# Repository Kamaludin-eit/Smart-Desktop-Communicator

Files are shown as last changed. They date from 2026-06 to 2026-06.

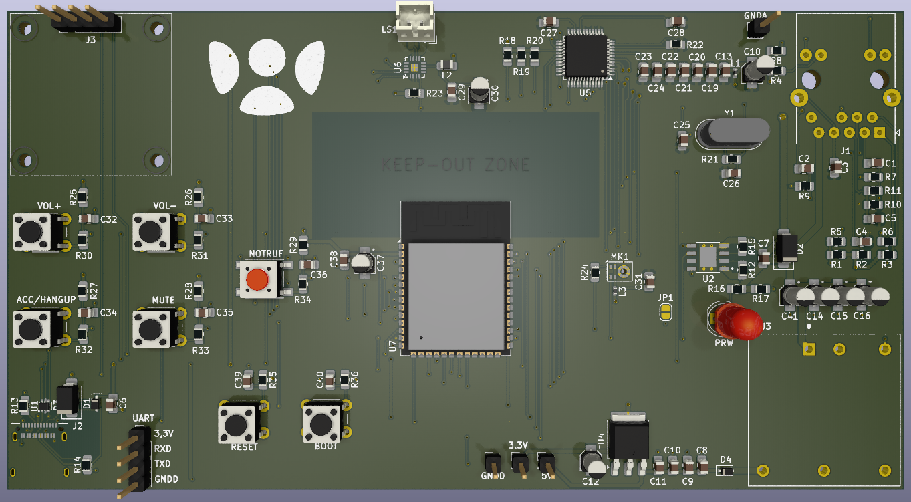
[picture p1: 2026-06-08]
docs/images/Chrood_PCB_image.png

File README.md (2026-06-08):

### Smart Desktop Communicator – Design-Dokumentation

**Rev 1.0 | Kamaludin Ali**

\---

#### Übersicht

ESP32-S3-basiertes stationäres IP-Telefon mit PoE-Versorgung, Wired Ethernet,
I2S-Audio und OLED-Display. 4-lagige PCB (150 × 80 mm).

\---

#### Wichtigste Design-Entscheidungen

##### 1\. Mikrocontroller – ESP32-S3-WROOM-1

* Dual-Core LX7, 16 MB Flash, 8 MB PSRAM, 2.4 GHz WLAN integriert
* Natives USB Serial/JTAG auf GPIO19/20 – kein separater USB-UART-Chip nötig
* I2S-Peripheral für DAC (MAX98357A) und PDM-Mikrofon (IM69D120) separat nutzbar
* SPI-Peripheral für W5500 Ethernet-Controller

##### 2\. PoE-Versorgung – TPS2378DDA + PDQE30-Q48-S5-D

* TPS2378DDA: IEEE 802.3at Type-2 PD-Controller (bis 30 W)
* Kein integrierter DC/DC – externer isolierter Wandler PDQE30 (48 V → 5 V, 30 W)
* Isolation trennt PWR\_GND (48 V-Seite) vollständig von GNDD/GNDA (Systemseite)
* Alternativversorgung via USB-C (5 V) mit Schottky-Dioden-OR-Schaltung#

##### 3\. RJ45-Connector – ARJP11A-MASA-B-A-EMU2 (Abracon)

* Integrierte Magnetics, Center-Tap, eingebauter Brückengleichrichter
* PRW+ (Pin 9) / PRW− (Pin 10): rektifizierte PoE-Spannung direkt abgreifbar
* Kein externer Brückengleichrichter oder separates Magnetics-Modul nötig
* Integrierte Status-LEDs (Link/Activity)

##### 4\. Ethernet – W5500

* Hardware-TCP/IP-Stack – entlastet ESP32-S3 vollständig
* SPI-Interface (bis 80 MHz), geringer Softwareaufwand

##### 5\. Audio-Ausgabe – MAX98357A

* I2S DAC + Class-D 3 W Verstärker in einem IC
* BTL-Ausgang: keine DC-Koppelkondensatoren am Lautsprecher nötig
* PVDD über Ferritperle L3 (600 Ω @ 100 MHz, 1 A) von 5V-Rail entkoppelt
* 3.3V-Logiksignale vom ESP32 kompatibel (VIH\_min = 1.5 V)
* Lautsprecher extern im Gehäuse montiert (akustische Echo-Minimierung)

##### 6\. Audio-Eingang – IM69D120 (Infineon)

* MEMS-Mikrofon mit PDM-Ausgang, SNR 69 dB, AOP 120 dB SPL
* Nativ vom ESP32-S3 PDM-Peripheral unterstützt
* VDD über eigene Ferritperle L4 (600 Ω @ 100 MHz, 50 mA) von VCCA\_MIC
* Software-AEC (Acoustic Echo Cancellation) via ESP-ADF

##### 7\. Massekonzept – 2 getrennte GND-Domänen

|Domäne|Verbindung|Komponenten|
|-|-|-|
|GNDD|Solder Jumper Pin 2 |ESP32, W5500 digital, Tasten, LEDs|
|GNDA|Solder Jumper Pin 1|W5500 PHY, IM69D120, MAX98357A, Quarz|

##### 8\. 4-Lagen PCB-Aufbau (150 × 80 mm)

|Lage|Inhalt|
|-|-|
|Layer 1 (Top)|Bauteile + Signale + GNDA-Kupferfläche|
|Layer 2 (In1)|+3,3V  |
|Layer 3 (In2)|GNDD-Kupferfläche|
|Layer 4 (Bottom)|Signale + GNDA-Kupferfläche|

* Digitale GND-Pads auf Top-Layer über Vias mit GNDD (In1) verbunden
* Analoge Komponenten direkt auf GNDA-Fläche (Top-Layer)

##### 9\. Versorgungsschienen

|Schiene|Quelle|Verbraucher|
|-|-|-|
|+48V\_POE|PRW+ via SMAJ58A|TPS2378DDA VDD|
|+5V|PDQE30 Ausgang|MAX98357A, AMS1117|
|+3.3V (VCCD)|AMS1117-3.3|ESP32, W5500 digital, Tasten, LEDs|
|VCCA\_ETH|VCCD via FB\_ETH (600Ω)|W5500 VCCA|
|VCCA\_MIC|VCCD via FB\_MIC (600Ω)|IM69D120 VDD|

### 

##### 10\. ESD-Schutz

|Interface|Schutz|
|-|-|
|PoE 48V|SMAJ58A (unidirektional, 58V)|
|USB-C VBUS|SMAJ5.0A (unidirektional, 5V)|
|USB-C D+/D−|USBLC6-2P6 (Low-C, bidirektional)|
|Ethernet TX/RX|Magnetics-Isolation im ARJP11A|

### 

##### 11\. USB-C – Amphenol 12401610E4#2A

* CC1/CC2: je 5.1 kΩ nach GNDD (5V UFP-Erkennung, kein PD-Controller nötig)
* Schottky-Diode OR-ing mit PoE-Versorgung
* D+/D−: direkt an ESP32 GPIO19/GPIO20 (natives USB JTAG/Serial)

##### 12\. HMI

* SSD1306 OLED 0.96" (128×64, I2C): Anrufstatus, IP, Uhrzeit
* 5 Taster: Annehmen/Auflegen, Vol+, Vol−, Stummschalten, Notruf
* 1 Status-LEDs:  Power(rot)
* Hardware-Entprellung: RC-Glied (100 kΩ + 1 µF) pro Taster

\---

#### Geplante Firmware-Architektur

* **ESP-IDF** v5.x + **ESP-ADF** (Audio Development Framework)
* SIP-Stack: sikorapatryk/sip-call oder OLIMEX/sip\_phone\_example als Referenz
* Codec: G.711 µ-law (PCMU, Payload Type 0)
* AEC: ESP-ADF eingebaut
* W5500-Treiber: arduino-ethernet oder esp-idf-w5500

\---

#### Wählscheibe

Nicht vorgesehen – Anrufsteuerung erfolgt über SIP-Server/PBX-Integration (z.B. FreePBX, Asterisk).

\---

## Revision History

|Rev|Datum|Änderung|
|-|-|-|
|1.0|2026-05|Erstversion|

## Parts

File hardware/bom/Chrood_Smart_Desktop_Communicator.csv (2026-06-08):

Reference | Value | Datasheet | Footprint | Qty | DNP
C1,C2 | 6,8nF | ~ | Capacitor_SMD:C_0805_2012Metric_Pad1.18x1.45mm_HandSolder | 2
C3 | 1nF | ~ | Capacitor_SMD:C_0805_2012Metric_Pad1.18x1.45mm_HandSolder | 1
C4 | 22nF | ~ | Capacitor_SMD:C_0805_2012Metric_Pad1.18x1.45mm_HandSolder | 1
C5 | 10nF | ~ | Capacitor_SMD:C_0805_2012Metric_Pad1.18x1.45mm_HandSolder | 1
C6 | 100nF | ~ | Capacitor_SMD:C_0805_2012Metric_Pad1.18x1.45mm_HandSolder | 1
C7,C8,C9,C10,C29,C31 | 100n | ~ | Capacitor_SMD:C_0805_2012Metric_Pad1.18x1.45mm_HandSolder | 6
C11,C13,C19,C20,C21,C22,C23,C24,C38,C39,C40 | 0,1u | ~ | Capacitor_SMD:C_0805_2012Metric_Pad1.18x1.45mm_HandSolder | 11
C12 | 47u | ~ | Capacitor_SMD:CP_Elec_3x5.3 | 1
C14,C15,C16,C41 | 22u | ~ | Capacitor_SMD:CP_Elec_3x5.3 | 4
C18,C30,C37 | 10u | ~ | Capacitor_SMD:CP_Elec_3x5.3 | 3
C25,C26 | 18p | ~ | Capacitor_SMD:C_0805_2012Metric_Pad1.18x1.45mm_HandSolder | 2
C27 | 10n | ~ | Capacitor_SMD:C_0805_2012Metric_Pad1.18x1.45mm_HandSolder | 1
C28 | 4,7u | ~ | Capacitor_SMD:C_0805_2012Metric_Pad1.18x1.45mm_HandSolder | 1
C32,C33,C34,C35,C36 | 2,2u | ~ | Capacitor_SMD:C_0805_2012Metric_Pad1.18x1.45mm_HandSolder | 5
D1,D4 | BAT54J | https://assets.nexperia.com/documents/data-sheet/BAT54J.pdf | Diode_SMD:D_SOD-323F | 2
D2 | SMAJ58A | https://www.littelfuse.com/media?itemid=75e32973-b177-4ee3-a0ff-cedaf1abdb93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 | Diode_SMD:D_SMA | 1
D3 | SMAJ5.0A | https://www.littelfuse.com/media?itemid=75e32973-b177-4ee3-a0ff-cedaf1abdb93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 | Diode_SMD:D_SMA | 1
D5 | LED | ~ | LED_THT:LED_D5.0mm | 1
J1 | RJ45_Abracon_ARJP11A-MASA-B-A-EMU2 | https://abracon.com/Magnetics/lan/ARJP11A.PDF | Connector_RJ:RJ45_Abracon_ARJP11A-MA_Horizontal | 1
J2 | USB_C_Receptacle_USB2.0_14P | https://www.usb.org/sites/default/files/documents/usb_type-c.zip | Connector_USB:USB_C_Receptacle_Amphenol_12401610E4-2A | 1
J3,J4 | Conn_01x04_Pin | ~ | Connector_PinHeader_2.54mm:PinHeader_1x04_P2.54mm_Vertical | 2
L1,L2,L3 | 600Ohm@100MHz | ~ | -- verschiedene Werte -- | 3
LS1 | Speaker | ~ | Connector_JST:JST_PH_B2B-PH-K_1x02_P2.00mm_Vertical | 1
MK1 | IM69D120 | https://www.infineon.com/dgdl/Infineon-IM69D120-DS-v01_00-EN.pdf?fileId=5546d462602a9dc801607a0e41a01a2b | Sensor_Audio:Infineon_PG-LLGA-5-1 | 1
R1,R2,R3 | 10 | ~ | Resistor_SMD:R_0805_2012Metric_Pad1.20x1.40mm_HandSolder | 3
R4,R8,R25,R26,R27,R28,R29 | 1k | ~ | Resistor_SMD:R_0805_2012Metric_Pad1.20x1.40mm_HandSolder | 7
R5,R6,R7,R9,R10,R11 | 33 | ~ | Resistor_SMD:R_0805_2012Metric_Pad1.20x1.40mm_HandSolder | 6
R12 | 24k9 | ~ | Resistor_SMD:R_0805_2012Metric_Pad1.20x1.40mm_HandSolder | 1
R13,R14 | 5,1k | ~ | Resistor_SMD:R_0805_2012Metric_Pad1.20x1.40mm_HandSolder | 2
R15 | 63R4 | ~ | Resistor_SMD:R_0805_2012Metric_Pad1.20x1.40mm_HandSolder | 1
R16 | 32k4 | ~ | Resistor_SMD:R_0805_2012Metric_Pad1.20x1.40mm_HandSolder | 1
R17 | 15k | ~ | Resistor_SMD:R_0805_2012Metric_Pad1.20x1.40mm_HandSolder | 1
R18,R19,R20,R35,R36 | 10k | ~ | Resistor_SMD:R_0805_2012Metric_Pad1.20x1.40mm_HandSolder | 5
R21 | 1M | ~ | Resistor_SMD:R_0805_2012Metric_Pad1.20x1.40mm_HandSolder | 1
R22 | 12k | ~ | Resistor_SMD:R_0805_2012Metric_Pad1.20x1.40mm_HandSolder | 1
R23 | 100k | ~ | Resistor_SMD:R_0805_2012Metric_Pad1.20x1.40mm_HandSolder | 1
R24 | 100 | ~ | Resistor_SMD:R_0805_2012Metric_Pad1.20x1.40mm_HandSolder | 1
R30,R31,R32,R33,R34 | 4,7k | ~ | Resistor_SMD:R_0805_2012Metric_Pad1.20x1.40mm_HandSolder | 5
SW1 | Vol+ | ~ | Button_Switch_THT:SW_PUSH_6mm | 1
SW2 | Vol- | ~ | Button_Switch_THT:SW_PUSH_6mm | 1
SW3 | Accept/Hang up | ~ | Button_Switch_THT:SW_PUSH_6mm | 1
SW4 | Mute | ~ | Button_Switch_THT:SW_PUSH_6mm | 1
SW5 | Notruf | ~ | Button_Switch_SMD:SW_SPST_PTS645 | 1
SW6,SW7 | SW_Push | ~ | Button_Switch_THT:SW_PUSH_6mm | 2
TP1,TP2,TP3,TP4 | TestPoint | ~ | Connector_PinHeader_2.54mm:PinHeader_1x01_P2.54mm_Vertical | 4
U1 | USBLC6-2P6 | https://www.st.com/resource/en/datasheet/usblc6-2.pdf | Package_TO_SOT_SMD:SOT-666 | 1
U2 | TPS2378DDA |  | TPS2378DDA:VREG_LM5017MR_NOPB | 1
U3 | PDQ30-Q48-S5-D |  | PDQ30-Q48-S5-D:CONV_PDQ30-Q48-S5-D | 1
U4 | AMS1117CD-3.3 | http://www.advanced-monolithic.com/pdf/ds1117.pdf | Package_TO_SOT_SMD:TO-252-3_TabPin2 | 1
U5 | W5500 | http://wizwiki.net/wiki/lib/exe/fetch.php/products:w5500:w5500_ds_v109e.pdf | Package_QFP:LQFP-48_7x7mm_P0.5mm | 1
U6 | MAX98357A | https://www.analog.com/media/en/technical-documentation/data-sheets/MAX98357A-MAX98357B.pdf | Package_DFN_QFN:TQFN-16-1EP_3x3mm_P0.5mm_EP1.23x1.23mm | 1
U7 | ESP32-S3-WROOM-1 | https://www.espressif.com/sites/default/files/documentation/esp32-s3-wroom-1_wroom-1u_datasheet_en.pdf | RF_Module:ESP32-S3-WROOM-1 | 1
Y1 | 25MHz | ~ | Crystal:Crystal_HC49-4H_Vertical | 1

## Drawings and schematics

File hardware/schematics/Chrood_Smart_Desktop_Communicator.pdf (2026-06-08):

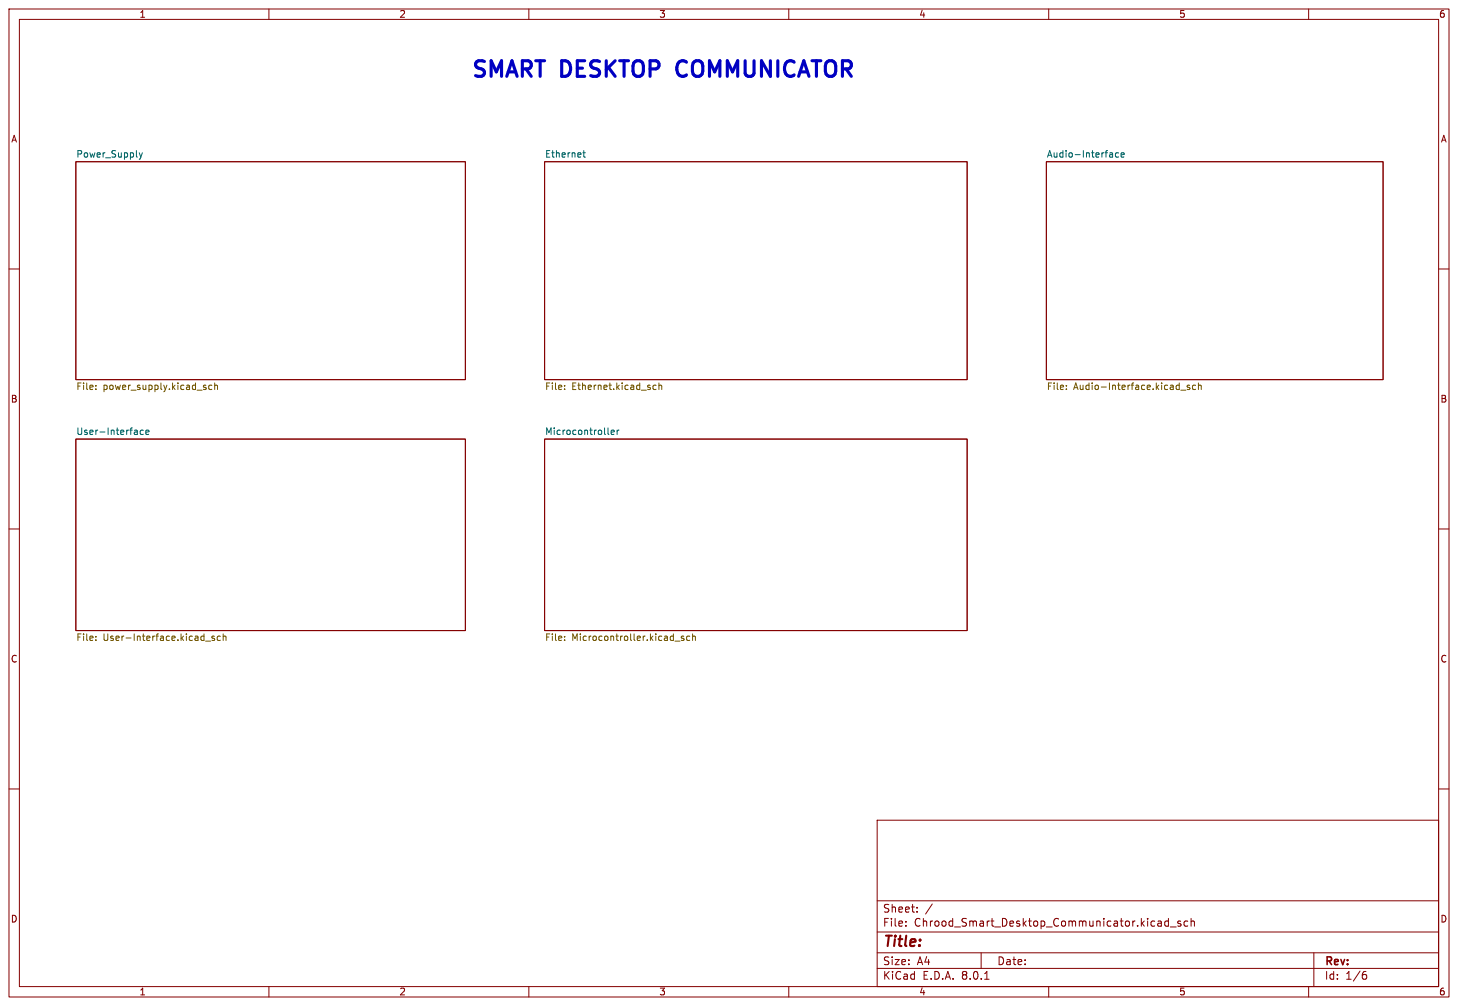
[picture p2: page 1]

User-Interface File: User-Interface.kicad_sch

Id: 1/6 Title: File: Chrood_Smart_Desktop_Communicator.kicad_sch Sheet: /

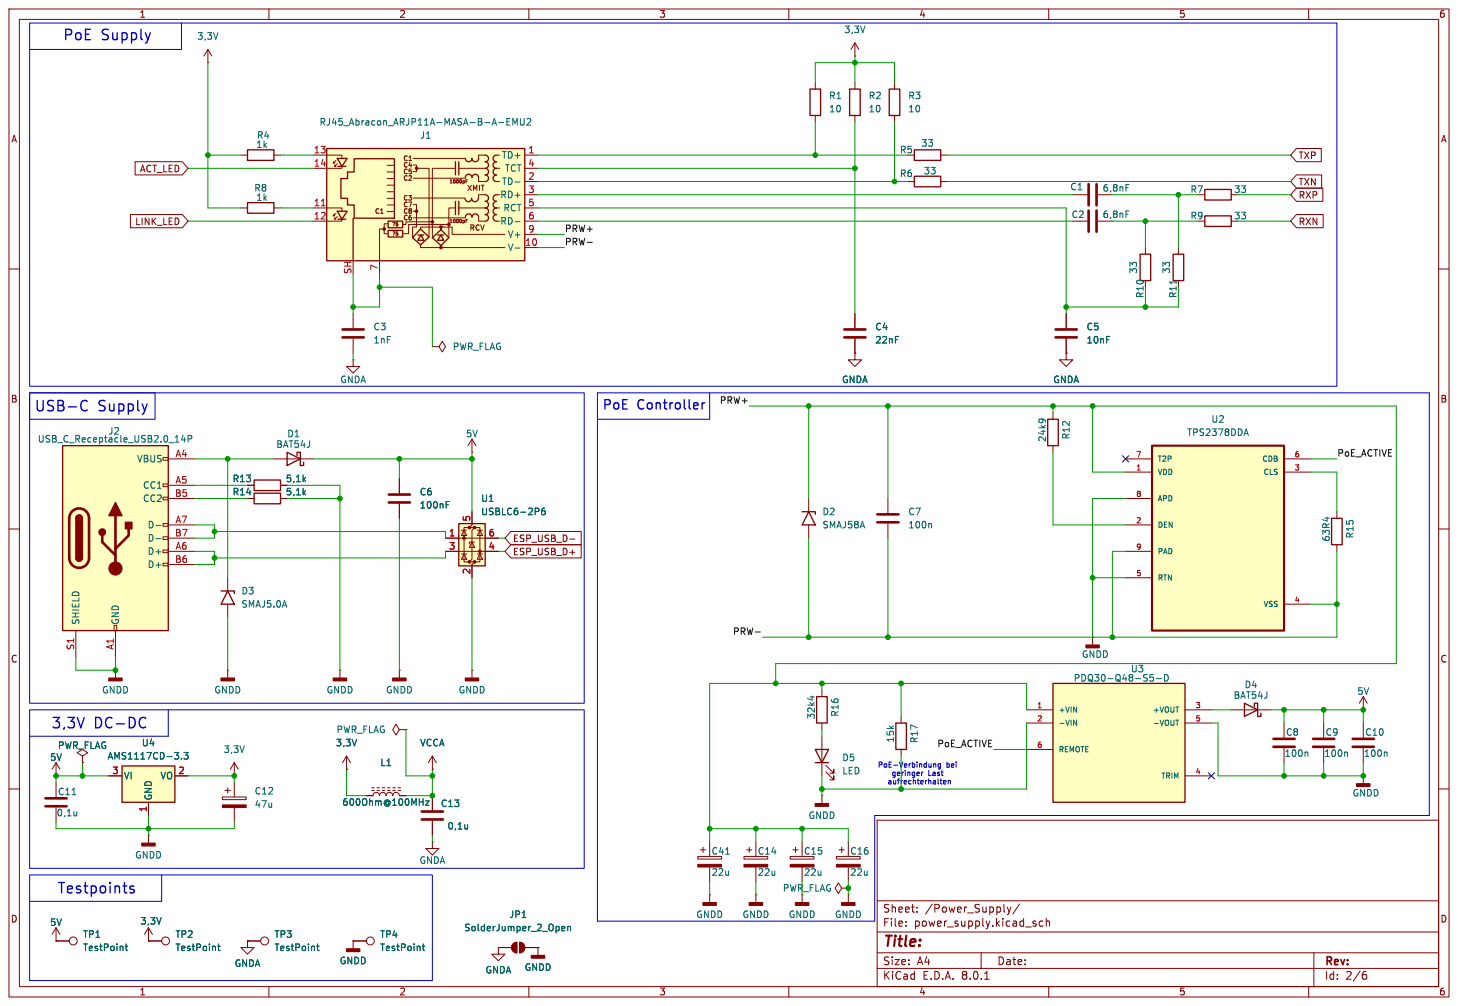
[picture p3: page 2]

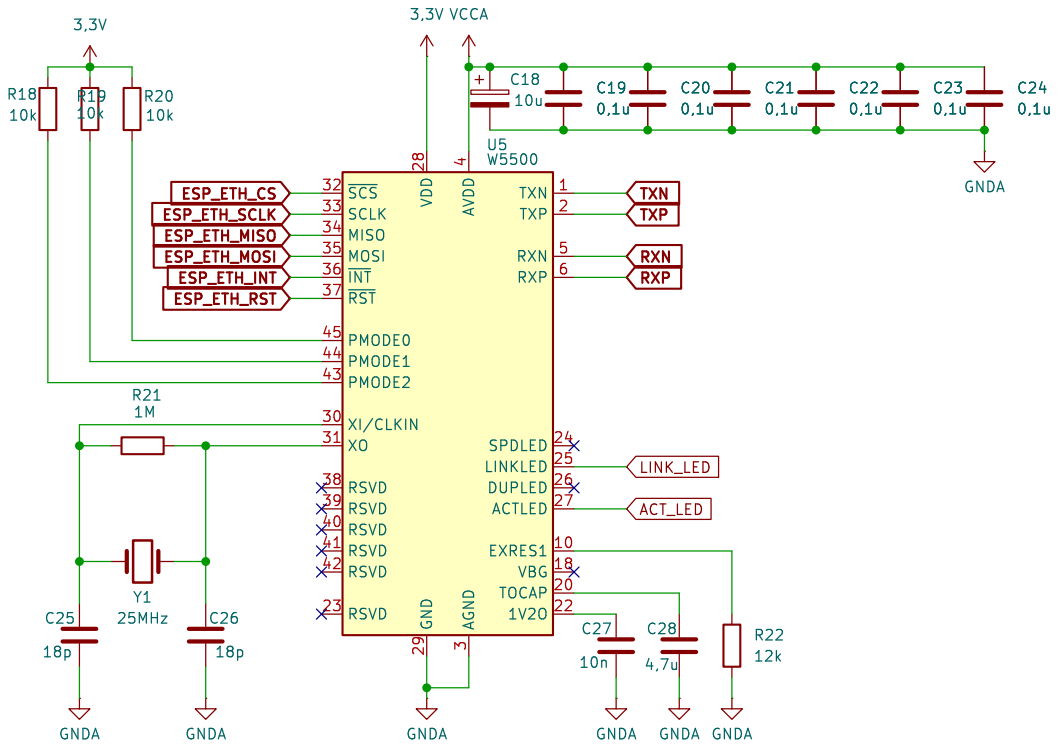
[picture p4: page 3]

Id: 3/6 Title: File: Ethernet.kicad_sch Sheet: /Ethernet/

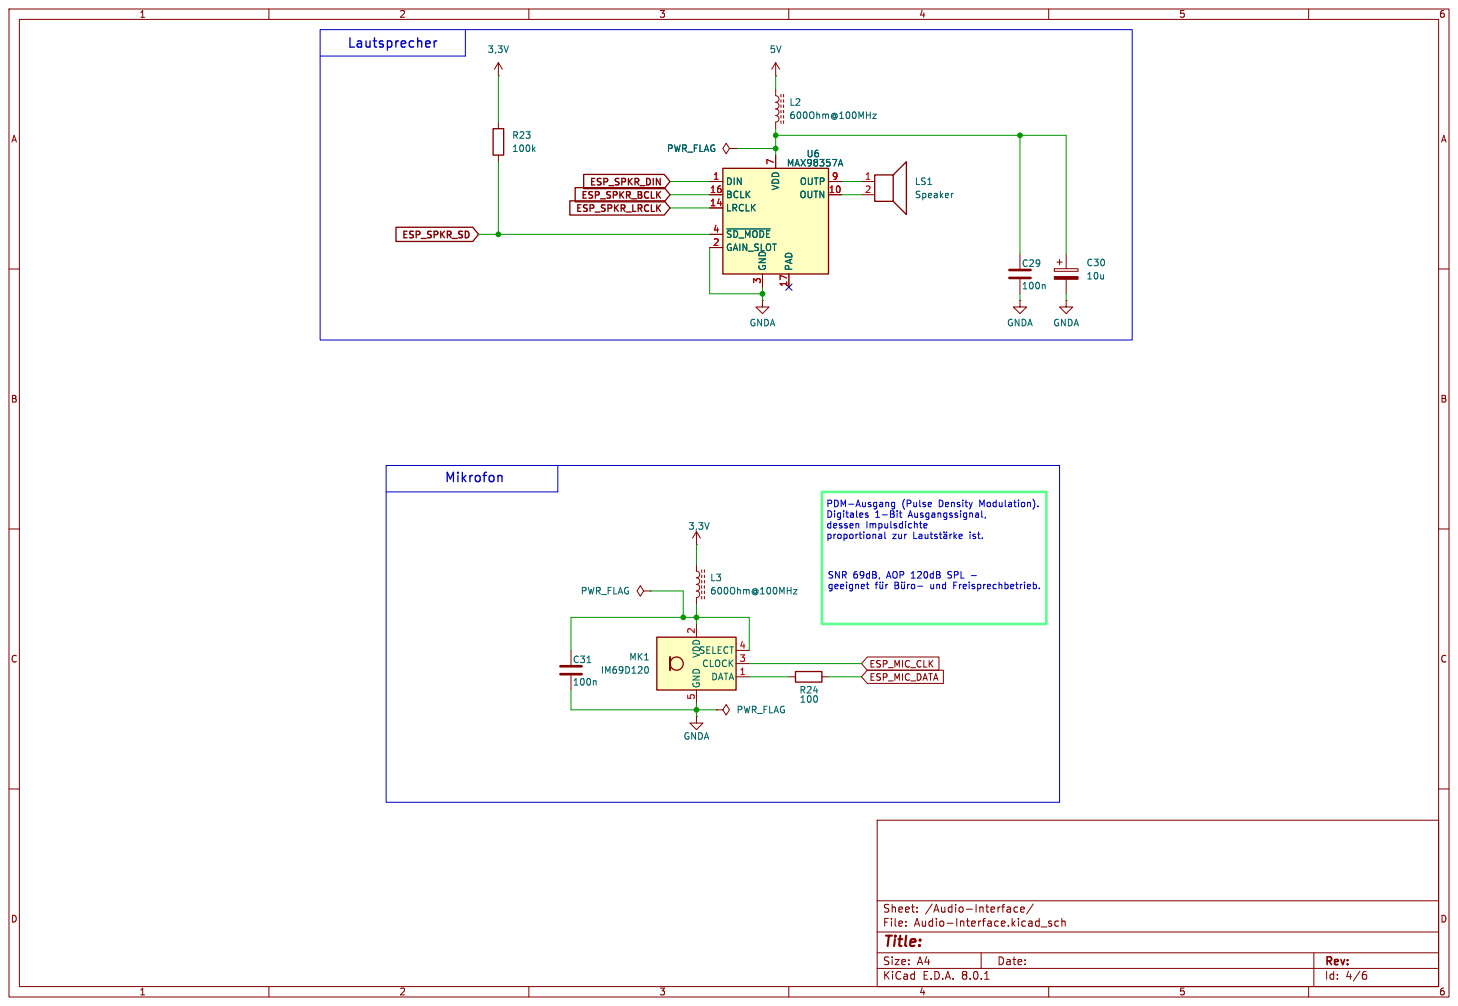
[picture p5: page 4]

Id: 4/6 Title: File: Audio-Interface.kicad_sch Sheet: /Audio-Interface/

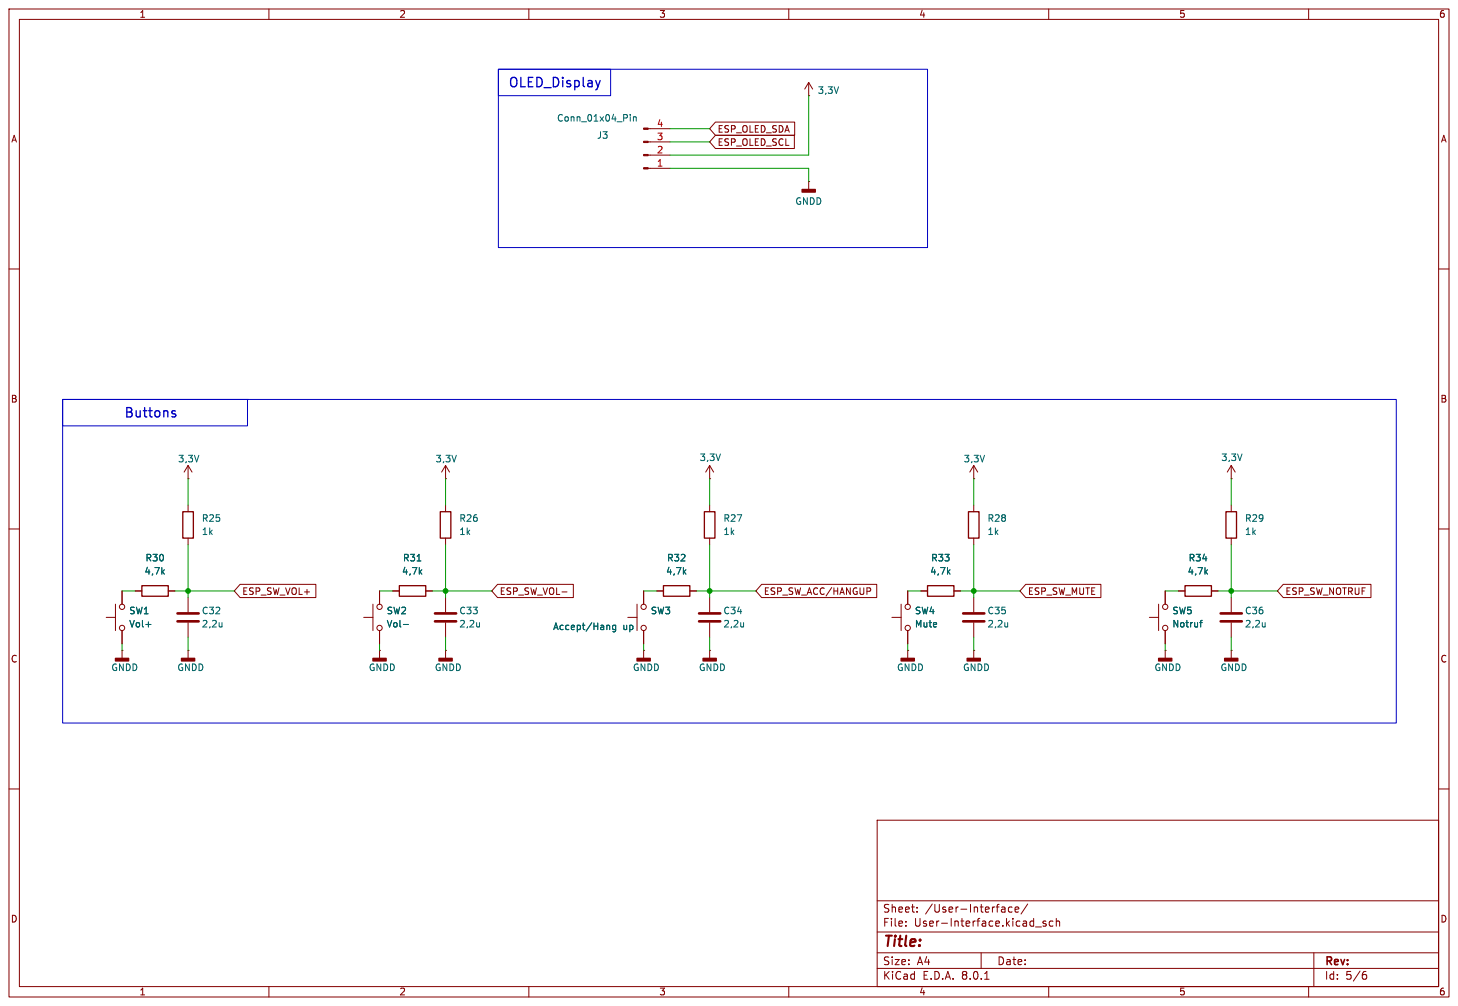
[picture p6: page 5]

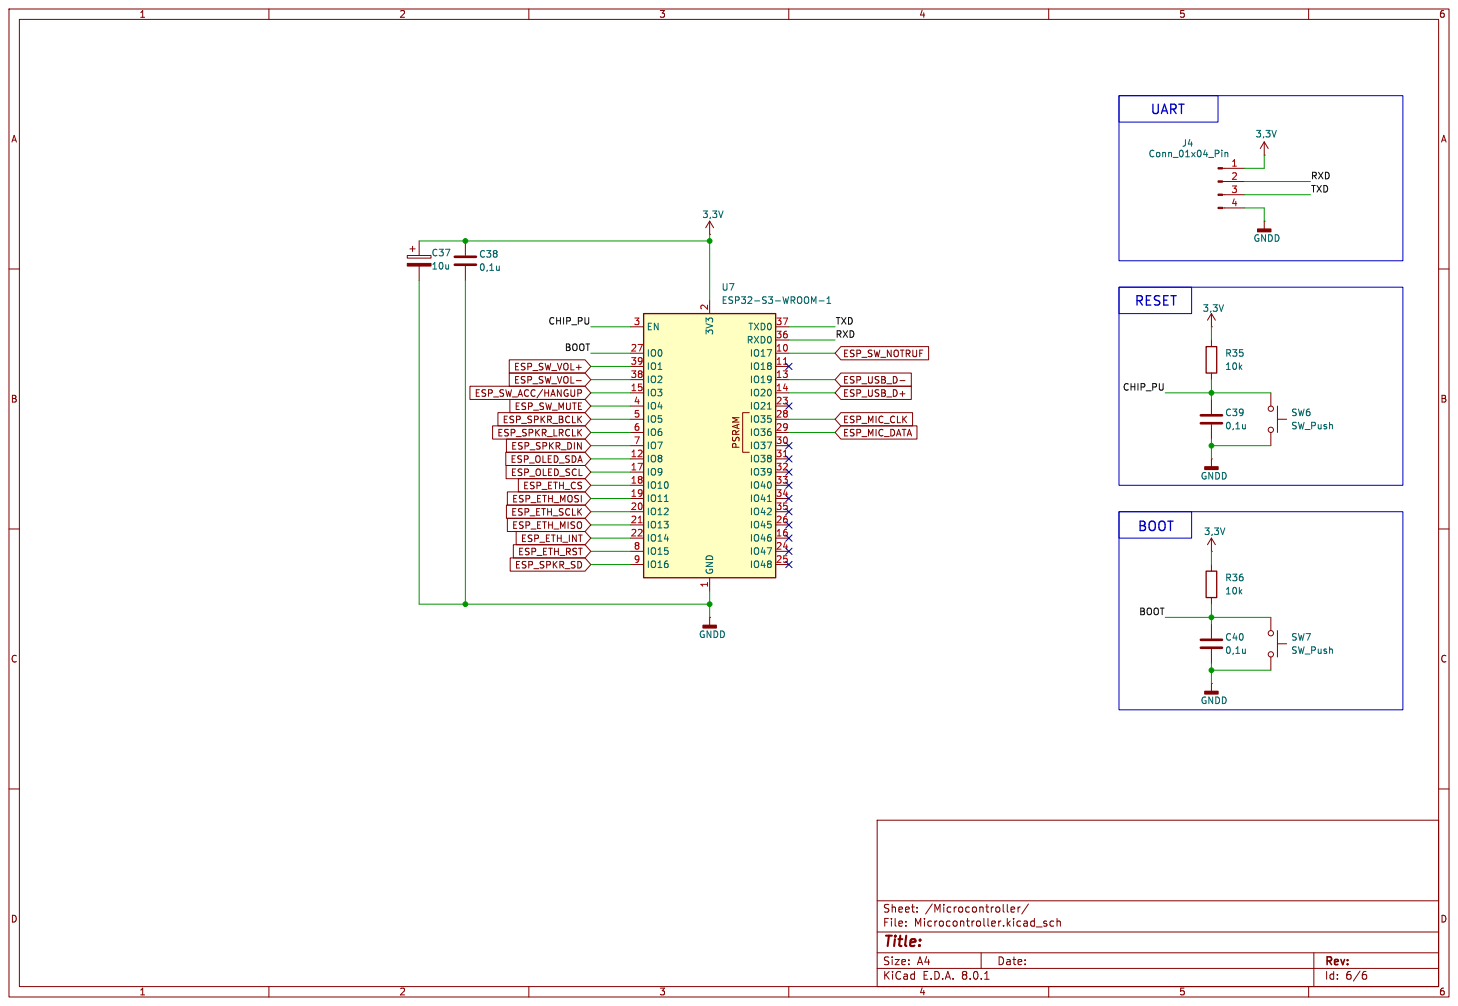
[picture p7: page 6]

Id: 6/6 Title: File: Microcontroller.kicad_sch Sheet: /Microcontroller/ GNDD

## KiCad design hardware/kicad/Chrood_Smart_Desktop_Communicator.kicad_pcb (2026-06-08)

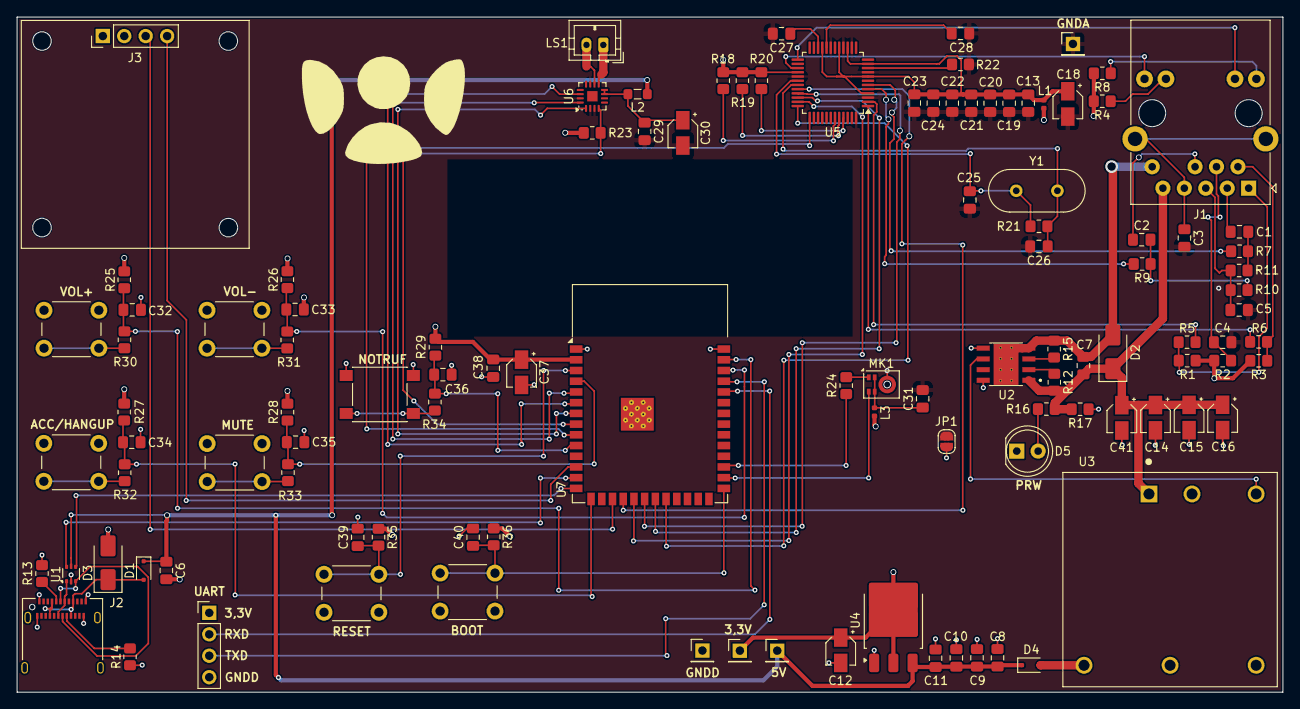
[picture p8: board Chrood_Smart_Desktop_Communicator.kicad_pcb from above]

Board: 4 copper layers, 150.0 x 80.0 mm, 110 parts (0 on the bottom side), 77 nets.

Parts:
C1, C2: 6,8nF; C_0805_2012Metric_Pad1.18x1.45mm_HandSolder
C3: 1nF; C_0805_2012Metric_Pad1.18x1.45mm_HandSolder
C4: 22nF; C_0805_2012Metric_Pad1.18x1.45mm_HandSolder
C5: 10nF; C_0805_2012Metric_Pad1.18x1.45mm_HandSolder
C6: 100nF; C_0805_2012Metric_Pad1.18x1.45mm_HandSolder
C7, C8, C9, C10, C29, C31: 100n; C_0805_2012Metric_Pad1.18x1.45mm_HandSolder
C11, C13, C19, C20, C21, C22, C23, C24, C38, C39, C40: 0,1u; C_0805_2012Metric_Pad1.18x1.45mm_HandSolder
C12: 47u; CP_Elec_3x5.3
C14, C15, C16, C41: 22u; CP_Elec_3x5.3
C18, C30, C37: 10u; CP_Elec_3x5.3
C25, C26: 18p; C_0805_2012Metric_Pad1.18x1.45mm_HandSolder
C27: 10n; C_0805_2012Metric_Pad1.18x1.45mm_HandSolder
C28: 4,7u; C_0805_2012Metric_Pad1.18x1.45mm_HandSolder
C32, C33, C34, C35, C36: 2,2u; C_0805_2012Metric_Pad1.18x1.45mm_HandSolder
D1, D4: BAT54J; D_SOD-323F
D2: SMAJ58A; D_SMA
D3: SMAJ5.0A; D_SMA
D5: LED; LED_D5.0mm
J1: RJ45_Abracon_ARJP11A-MASA-B-A-EMU2; RJ45_Abracon_ARJP11A-MA_Horizontal
J2: USB_C_Receptacle_USB2.0_14P; USB_C_Receptacle_Amphenol_12401610E4-2A
J3, J4: Conn_01x04_Pin; PinHeader_1x04_P2.54mm_Vertical
JP1: SolderJumper_2_Open; SolderJumper-2_P1.3mm_Open_RoundedPad1.0x1.5mm
L1, L3: 600Ohm@100MHz; L_0402_1005Metric
L2: 600Ohm@100MHz; L_0805_2012Metric_Pad1.05x1.20mm_HandSolder
LS1: Speaker; JST_PH_B2B-PH-K_1x02_P2.00mm_Vertical
MK1: IM69D120; Infineon_PG-LLGA-5-1
R1, R2, R3: 10; R_0805_2012Metric_Pad1.20x1.40mm_HandSolder
R4, R8, R25, R26, R27, R28, R29: 1k; R_0805_2012Metric_Pad1.20x1.40mm_HandSolder
R5, R6, R7, R9, R10, R11: 33; R_0805_2012Metric_Pad1.20x1.40mm_HandSolder
R12: 24k9; R_0805_2012Metric_Pad1.20x1.40mm_HandSolder
R13, R14: 5,1k; R_0805_2012Metric_Pad1.20x1.40mm_HandSolder
R15: 63R4; R_0805_2012Metric_Pad1.20x1.40mm_HandSolder
R16: 32k4; R_0805_2012Metric_Pad1.20x1.40mm_HandSolder
R17: 15k; R_0805_2012Metric_Pad1.20x1.40mm_HandSolder
R18, R19, R20, R35, R36: 10k; R_0805_2012Metric_Pad1.20x1.40mm_HandSolder
R21: 1M; R_0805_2012Metric_Pad1.20x1.40mm_HandSolder
R22: 12k; R_0805_2012Metric_Pad1.20x1.40mm_HandSolder
R23: 100k; R_0805_2012Metric_Pad1.20x1.40mm_HandSolder
R24: 100; R_0805_2012Metric_Pad1.20x1.40mm_HandSolder
R30, R31, R32, R33, R34: 4,7k; R_0805_2012Metric_Pad1.20x1.40mm_HandSolder
SW1: Vol+; SW_PUSH_6mm
SW2: Vol-; SW_PUSH_6mm
SW3: Accept/Hang up; SW_PUSH_6mm
SW4: Mute; SW_PUSH_6mm
SW5: Notruf; SW_SPST_PTS645
SW6, SW7: SW_Push; SW_PUSH_6mm
TP1, TP2, TP3, TP4: TestPoint; PinHeader_1x01_P2.54mm_Vertical
U1: USBLC6-2P6; SOT-666
U2: TPS2378DDA; VREG_LM5017MR_NOPB
U3: PDQ30-Q48-S5-D; CONV_PDQ30-Q48-S5-D
U4: AMS1117CD-3.3; TO-252-3_TabPin2
U5: W5500; LQFP-48_7x7mm_P0.5mm
U6: MAX98357A; TQFN-16-1EP_3x3mm_P0.5mm_EP1.23x1.23mm
U7: ESP32-S3-WROOM-1
Y1: 25MHz; Crystal_HC49-4H_Vertical

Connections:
3,3V: C12.1, C37.1, C38.1, J3.2, J4.1, L1.1, L3.1, R1.2, R2.2, R3.2, R4.2, R8.2, R18.1, R19.1, R20.1, R23.1, R25.2, R26.2, R27.2, R28.2, R29.2, R35.1, R36.1, TP2.1, U4.2 (VO), U5.28 (VDD), U7.2 (3V3)
5V: C6.1, C8.1, C9.1, C10.1, C11.1, D1.1 (K), D4.1 (K), L2.1, TP1.1, U1.5 (VBUS), U4.3 (VI)
/Microcontroller/BOOT: C40.1, R36.2, SW7.1, U7.27 (IO0)
/Microcontroller/CHIP_PU: C39.1, R35.2, SW6.1, U7.3 (EN)
/Microcontroller/RXD: J4.2, U7.36 (RXD0)
/Microcontroller/TXD: J4.3, U7.37 (TXD0)
/Power_Supply/PRW+: C7.1, C14.1, C15.1, C16.1, C41.1, D2.1 (A1), J1.9 (V+), R12.2, R16.2, R17.2, U2.1 (VDD), U3.1 (+VIN)
/Power_Supply/PRW-: C7.2, D2.2 (A2), J1.10 (V-), R15.1, U2.4 (VSS), U2.9 (PAD)
/Power_Supply/PoE_ACTIVE: U2.6 (CDB), U3.6 (REMOTE)
ACT_LED: J1.14, U5.27 (ACTLED)
ESP_ETH_CS: U5.32 (~SCS), U7.18 (IO10)
ESP_ETH_INT: U5.36 (~INT), U7.22 (IO14)
ESP_ETH_MISO: U5.34 (MISO), U7.21 (IO13)
ESP_ETH_MOSI: U5.35 (MOSI), U7.19 (IO11)
ESP_ETH_RST: U5.37 (~RST), U7.8 (IO15)
ESP_ETH_SCLK: U5.33 (SCLK), U7.20 (IO12)
ESP_MIC_CLK: MK1.3 (CLOCK), U7.28 (IO35)
ESP_MIC_DATA: R24.2, U7.29 (IO36)
ESP_OLED_SCL: J3.3, U7.17 (IO9)
ESP_OLED_SDA: J3.4, U7.12 (IO8)
ESP_SPKR_BCLK: U6.16 (BCLK), U7.5 (IO5)
ESP_SPKR_DIN: U6.1 (DIN), U7.7 (IO7)
ESP_SPKR_LRCLK: U6.14 (LRCLK), U7.6 (IO6)
ESP_SPKR_SD: R23.2, U6.4 (~SD_MODE), U7.9 (IO16)
ESP_SW_ACC/HANGUP: C34.1, R27.1, R32.2, U7.15 (IO3)
ESP_SW_MUTE: C35.1, R28.1, R33.2, U7.4 (IO4)
ESP_SW_NOTRUF: C36.1, R29.1, R34.2, U7.10 (IO17)
ESP_SW_VOL+: C32.1, R25.1, R30.2, U7.39 (IO1)
ESP_SW_VOL-: C33.1, R26.1, R31.2, U7.38 (IO2)
ESP_USB_D+: U1.4 (I/O2), U7.14 (IO20)
ESP_USB_D-: U1.6 (I/O1), U7.13 (IO19)
GNDA: C3.2, C4.2, C5.2, C13.2, C18.2, C19.2, C20.2, C21.2, C22.2, C23.2, C24.2, C25.2, C26.2, C27.2, C28.2, C29.2, C30.2, C31.2, JP1.1 (A), MK1.5 (GND), R22.2, TP3.1, U5.3 (AGND), U5.9 (AGND), U5.14 (AGND), U5.16 (AGND), U5.19 (AGND), U5.29 (GND), U5.48 (AGND), U6.2 (GAIN_SLOT), U6.3 (GND), U6.11 (GND), U6.15 (GND)
GNDD: C6.2, C8.2, C9.2, C10.2, C11.2, C12.2, C14.2, C15.2, C16.2, C32.2, C33.2, C34.2, C35.2, C36.2, C37.2, C38.2, C39.2, C40.2, C41.2, D3.2 (A2), D5.1 (K), J2.A1 (GND), J2.A12 (GND), J2.B1 (GND), J2.B12 (GND), J2.S1 (SHIELD), J3.1, J4.4, JP1.2 (B), R13.1, R14.1, R17.1, SW1.1, SW2.1, SW3.1, SW4.1, SW5.1, SW6.2, SW7.2, TP4.1, U1.2 (GND), U2.5 (RTN), U2.8 (APD), U3.2 (-VIN), U3.5 (-VOUT), U4.1 (GND), U7.1 (GND), U7.40 (GND), U7.41 (GND)
LINK_LED: J1.12, U5.25 (LINKLED)
unnamed: C1.2, R7.1, R11.2
unnamed: C2.2, R9.1, R10.2
unnamed: C3.1, J1.7, J1.SH
unnamed: C29.1, C30.1, L2.2, U6.7 (VDD), U6.8 (VDD)
unnamed: D1.2 (A), D3.1 (A1), J2.A4 (VBUS), J2.A9 (VBUS), J2.B4 (VBUS), J2.B9 (VBUS)
unnamed: D4.2 (A), U3.3 (+VOUT)
unnamed: D5.2 (A), R16.1
unnamed: J1.11, R8.1
unnamed: J1.13, R4.1
unnamed: C5.1, J1.5 (RCT), R10.1, R11.1
unnamed: C1.1, J1.3 (RD+)
unnamed: C2.1, J1.6 (RD-)
unnamed: C4.1, J1.4 (TCT), R2.1
unnamed: J1.1 (TD+), R1.1, R5.1
unnamed: J1.2 (TD-), R3.1, R6.1
unnamed: J2.A5 (CC1), R13.2
unnamed: J2.B5 (CC2), R14.2
unnamed: J2.A6 (D+), J2.B6 (D+), U1.3 (I/O2)
unnamed: J2.A7 (D-), J2.B7 (D-), U1.1 (I/O1)
unnamed: MK1.1 (DATA), R24.1
unnamed: C31.1, L3.2, MK1.2 (VDD), MK1.4 (SELECT)
unnamed: R30.1, SW1.2
unnamed: R31.1, SW2.2
unnamed: R32.1, SW3.2
unnamed: R33.1, SW4.2
unnamed: R34.1, SW5.2
unnamed: R15.2, U2.3 (CLS)
unnamed: R12.1, U2.2 (DEN)
unnamed: C27.1, U5.22 (1V2O)
unnamed: R22.1, U5.10 (EXRES1)
unnamed: R20.2, U5.45 (PMODE0)
unnamed: R19.2, U5.44 (PMODE1)
unnamed: R18.2, U5.43 (PMODE2)
unnamed: C28.1, U5.20 (TOCAP)
unnamed: C25.1, R21.1, U5.30 (XI/CLKIN), Y1.1
unnamed: C26.1, R21.2, U5.31 (XO), Y1.2
unnamed: LS1.2, U6.10 (OUTN)
unnamed: LS1.1, U6.9 (OUTP)
RXN: R9.2, U5.5 (RXN)
RXP: R7.2, U5.6 (RXP)
TXN: R6.2, U5.1 (TXN)
TXP: R5.2, U5.2 (TXP)
VCCA: C13.1, C18.1, C19.1, C20.1, C21.1, C22.1, C23.1, C24.1, L1.2, U5.4 (AVDD), U5.8 (AVDD), U5.11 (AVDD), U5.15 (AVDD), U5.17 (AVDD), U5.21 (AVDD)

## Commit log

2026-06-08 Add files via upload
    Hardware: Add KiCad project files
    [Chrood_Smart_Desktop_Communicator.kicad_pcb, Chrood_Smart_Desktop_Communicator.kicad_sch]
2026-06-08 Add files via upload
    Hardware: Add schematic PDFs all 5 sheets
2026-06-08 Add files via upload
    Hardware: Add Bill of Materials Rev 1.0
    [Chrood_Smart_Desktop_Communicator.csv]
2026-06-08 Add files via upload
    Docs: Add PCB layout preview
